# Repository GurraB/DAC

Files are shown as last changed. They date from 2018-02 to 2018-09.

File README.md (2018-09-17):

# DAC
A USB DAC

This is my take on an USB DAC. 

Theoretical specs:
- 16 bit resolution
- fs = 44.1 kHz
- Signal to noise ratio: 127 dB
- THD+N: 0.0004%

Components:

- TI PCM2707c http://www.ti.com/lit/ds/sbfs036b/sbfs036b.pdf
- TI PCM1794a http://www.ti.com/lit/ds/symlink/pcm1794a.pdf
- TI OPA2134 http://www.ti.com/lit/ds/symlink/opa2134.pdf
- TI LM2662 http://www.ti.com/lit/ds/symlink/lm2663.pdf
- TI TPS60501 http://www.ti.com/lit/ds/symlink/tps60500.pdf

This was designed in EAGLE CAD. It is the first PCB I have ever made. The PCM2707c is used as an USB interface, it is automatically detected as a DAC by windows (Linux might need some drivers). The PCM2707c converts the USB signal to i2s and sends it to the PCM1794a. PCM1794a is a high quality DAC that generates the output signal. The signal is then sent to the operational amplifier.

The bottleneck in the system is the PCM2707c since it can only accept 16 bit audio signal.

Future work:
This is the first design that I have made to see if I can make a simple DAC to begin with. In the future I have plans to add an ESP32 to allow for bluetooth connectivity. I have also thought about adding a Raspberry Pi Zero W that can act as a spotify connect device.

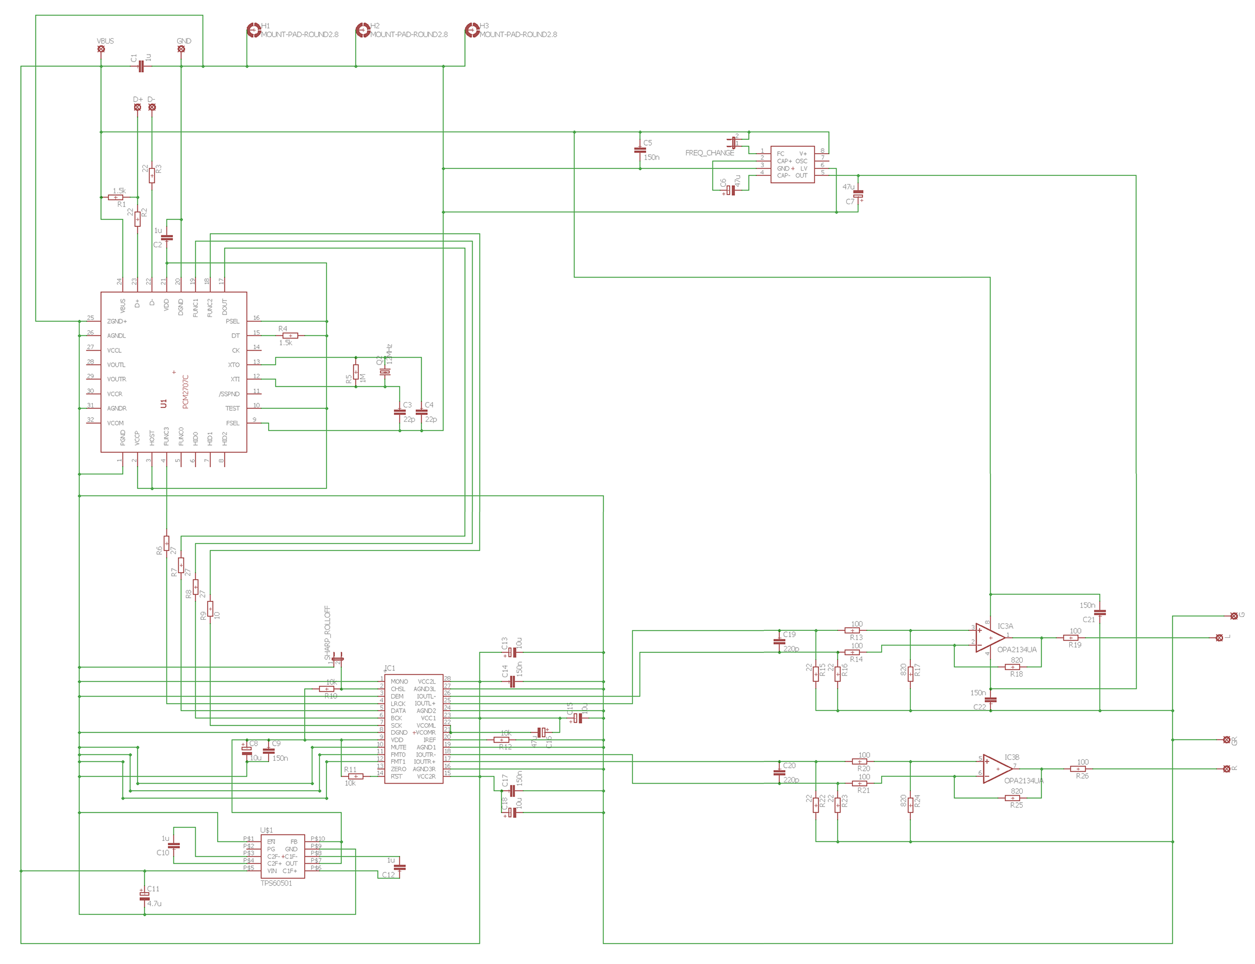
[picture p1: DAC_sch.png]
Picture of the schematic

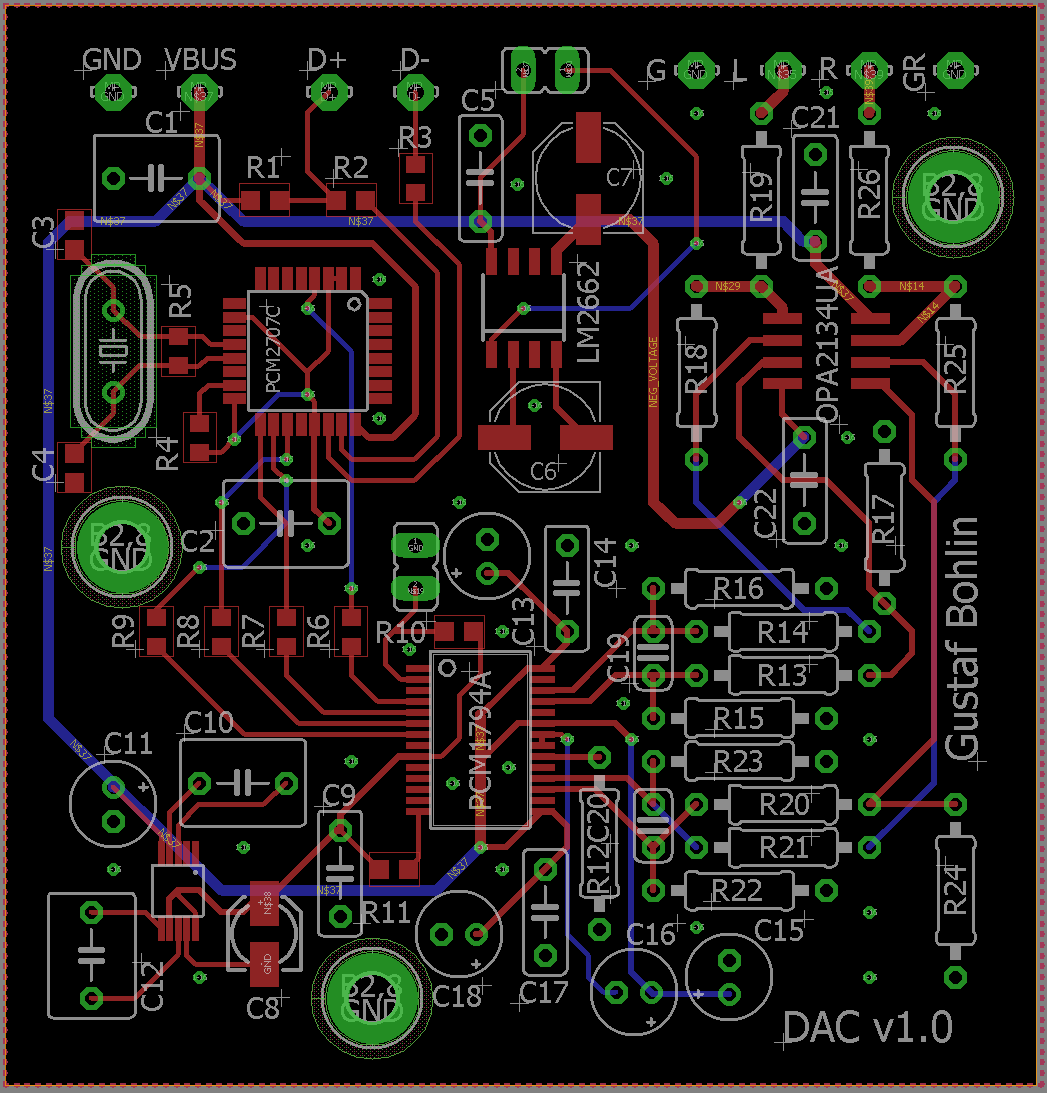
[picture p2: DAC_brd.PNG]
Picture of the board layout

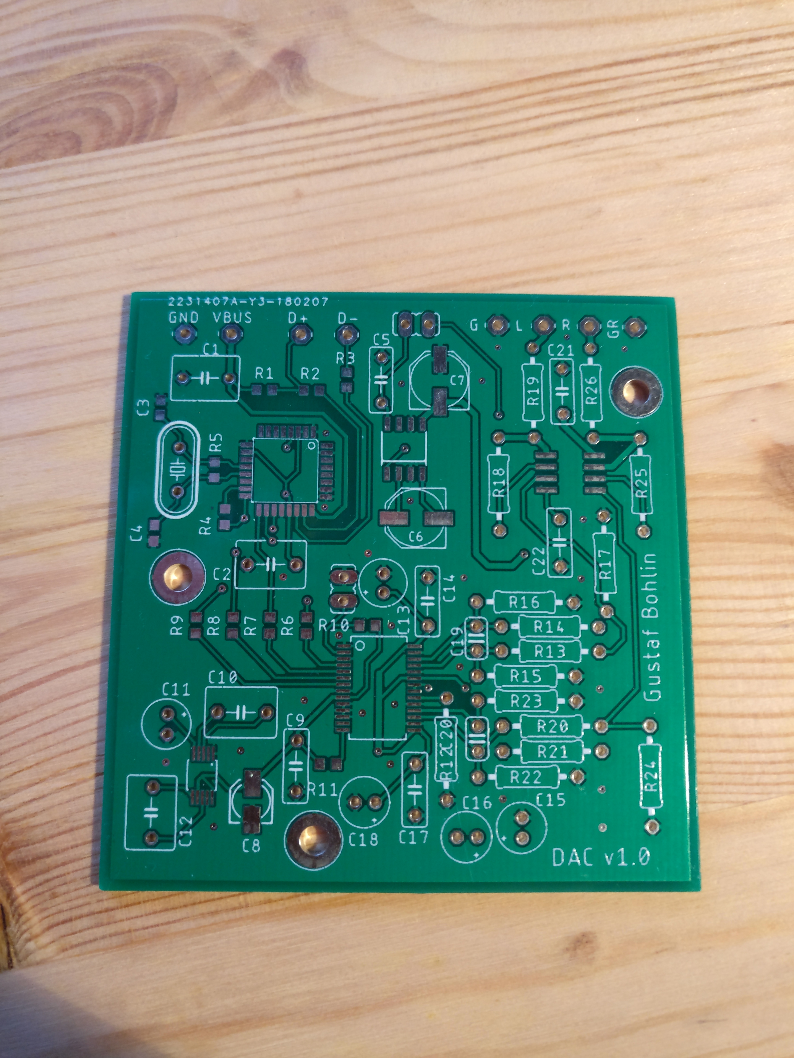
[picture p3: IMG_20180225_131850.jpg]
Picture of finished board without components

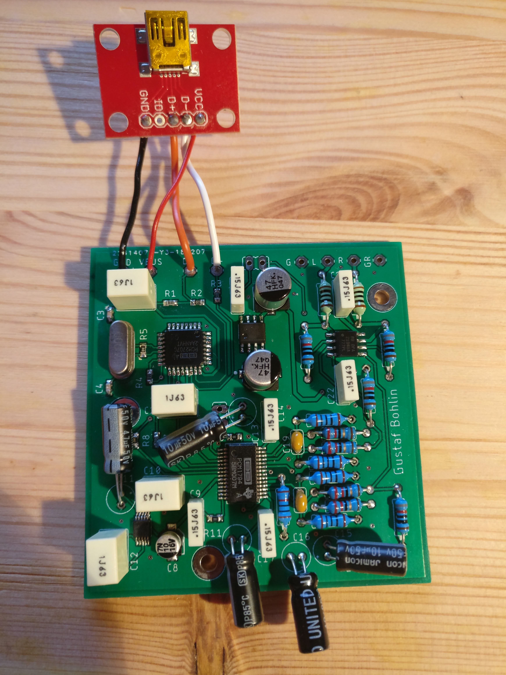
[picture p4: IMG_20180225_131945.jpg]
Picture of finished board with components

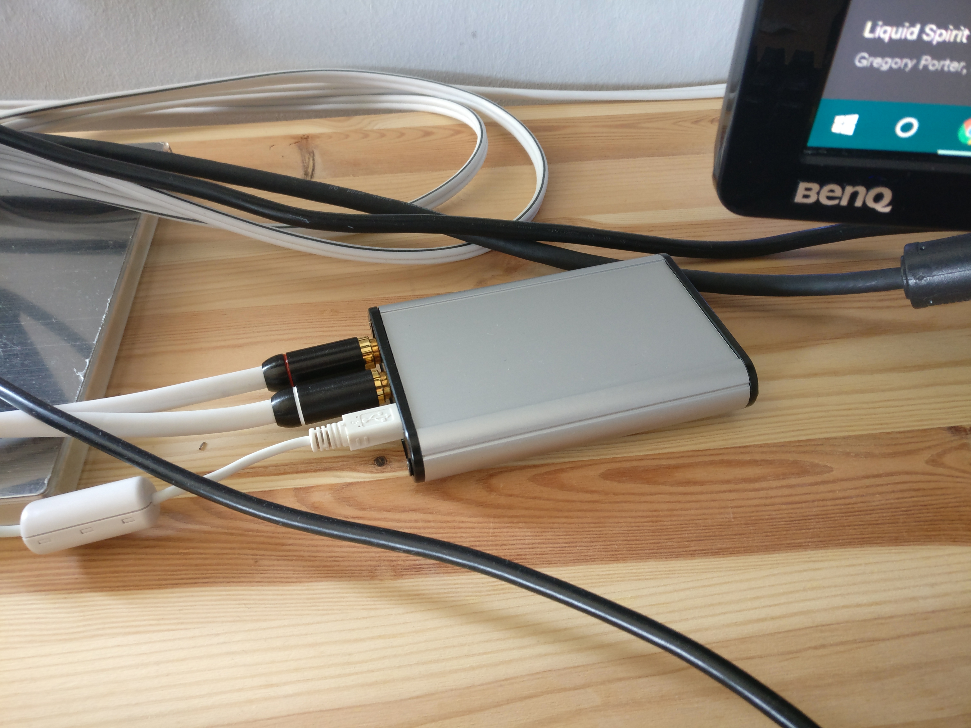
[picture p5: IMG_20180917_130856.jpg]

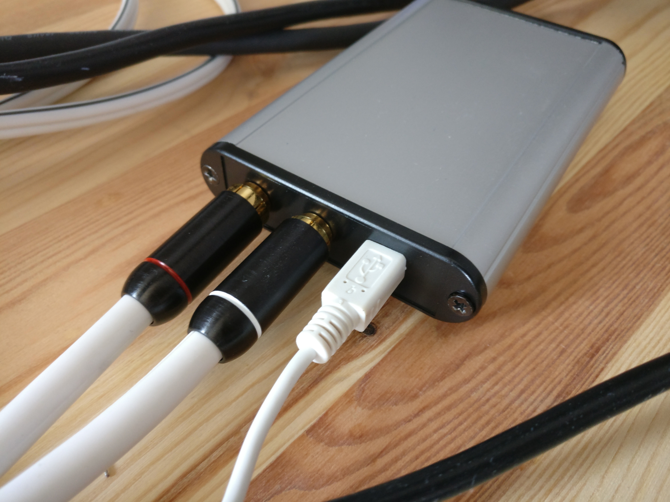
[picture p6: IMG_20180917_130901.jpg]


Design is based upon http://users.abo.fi/jskata/JEDAC/

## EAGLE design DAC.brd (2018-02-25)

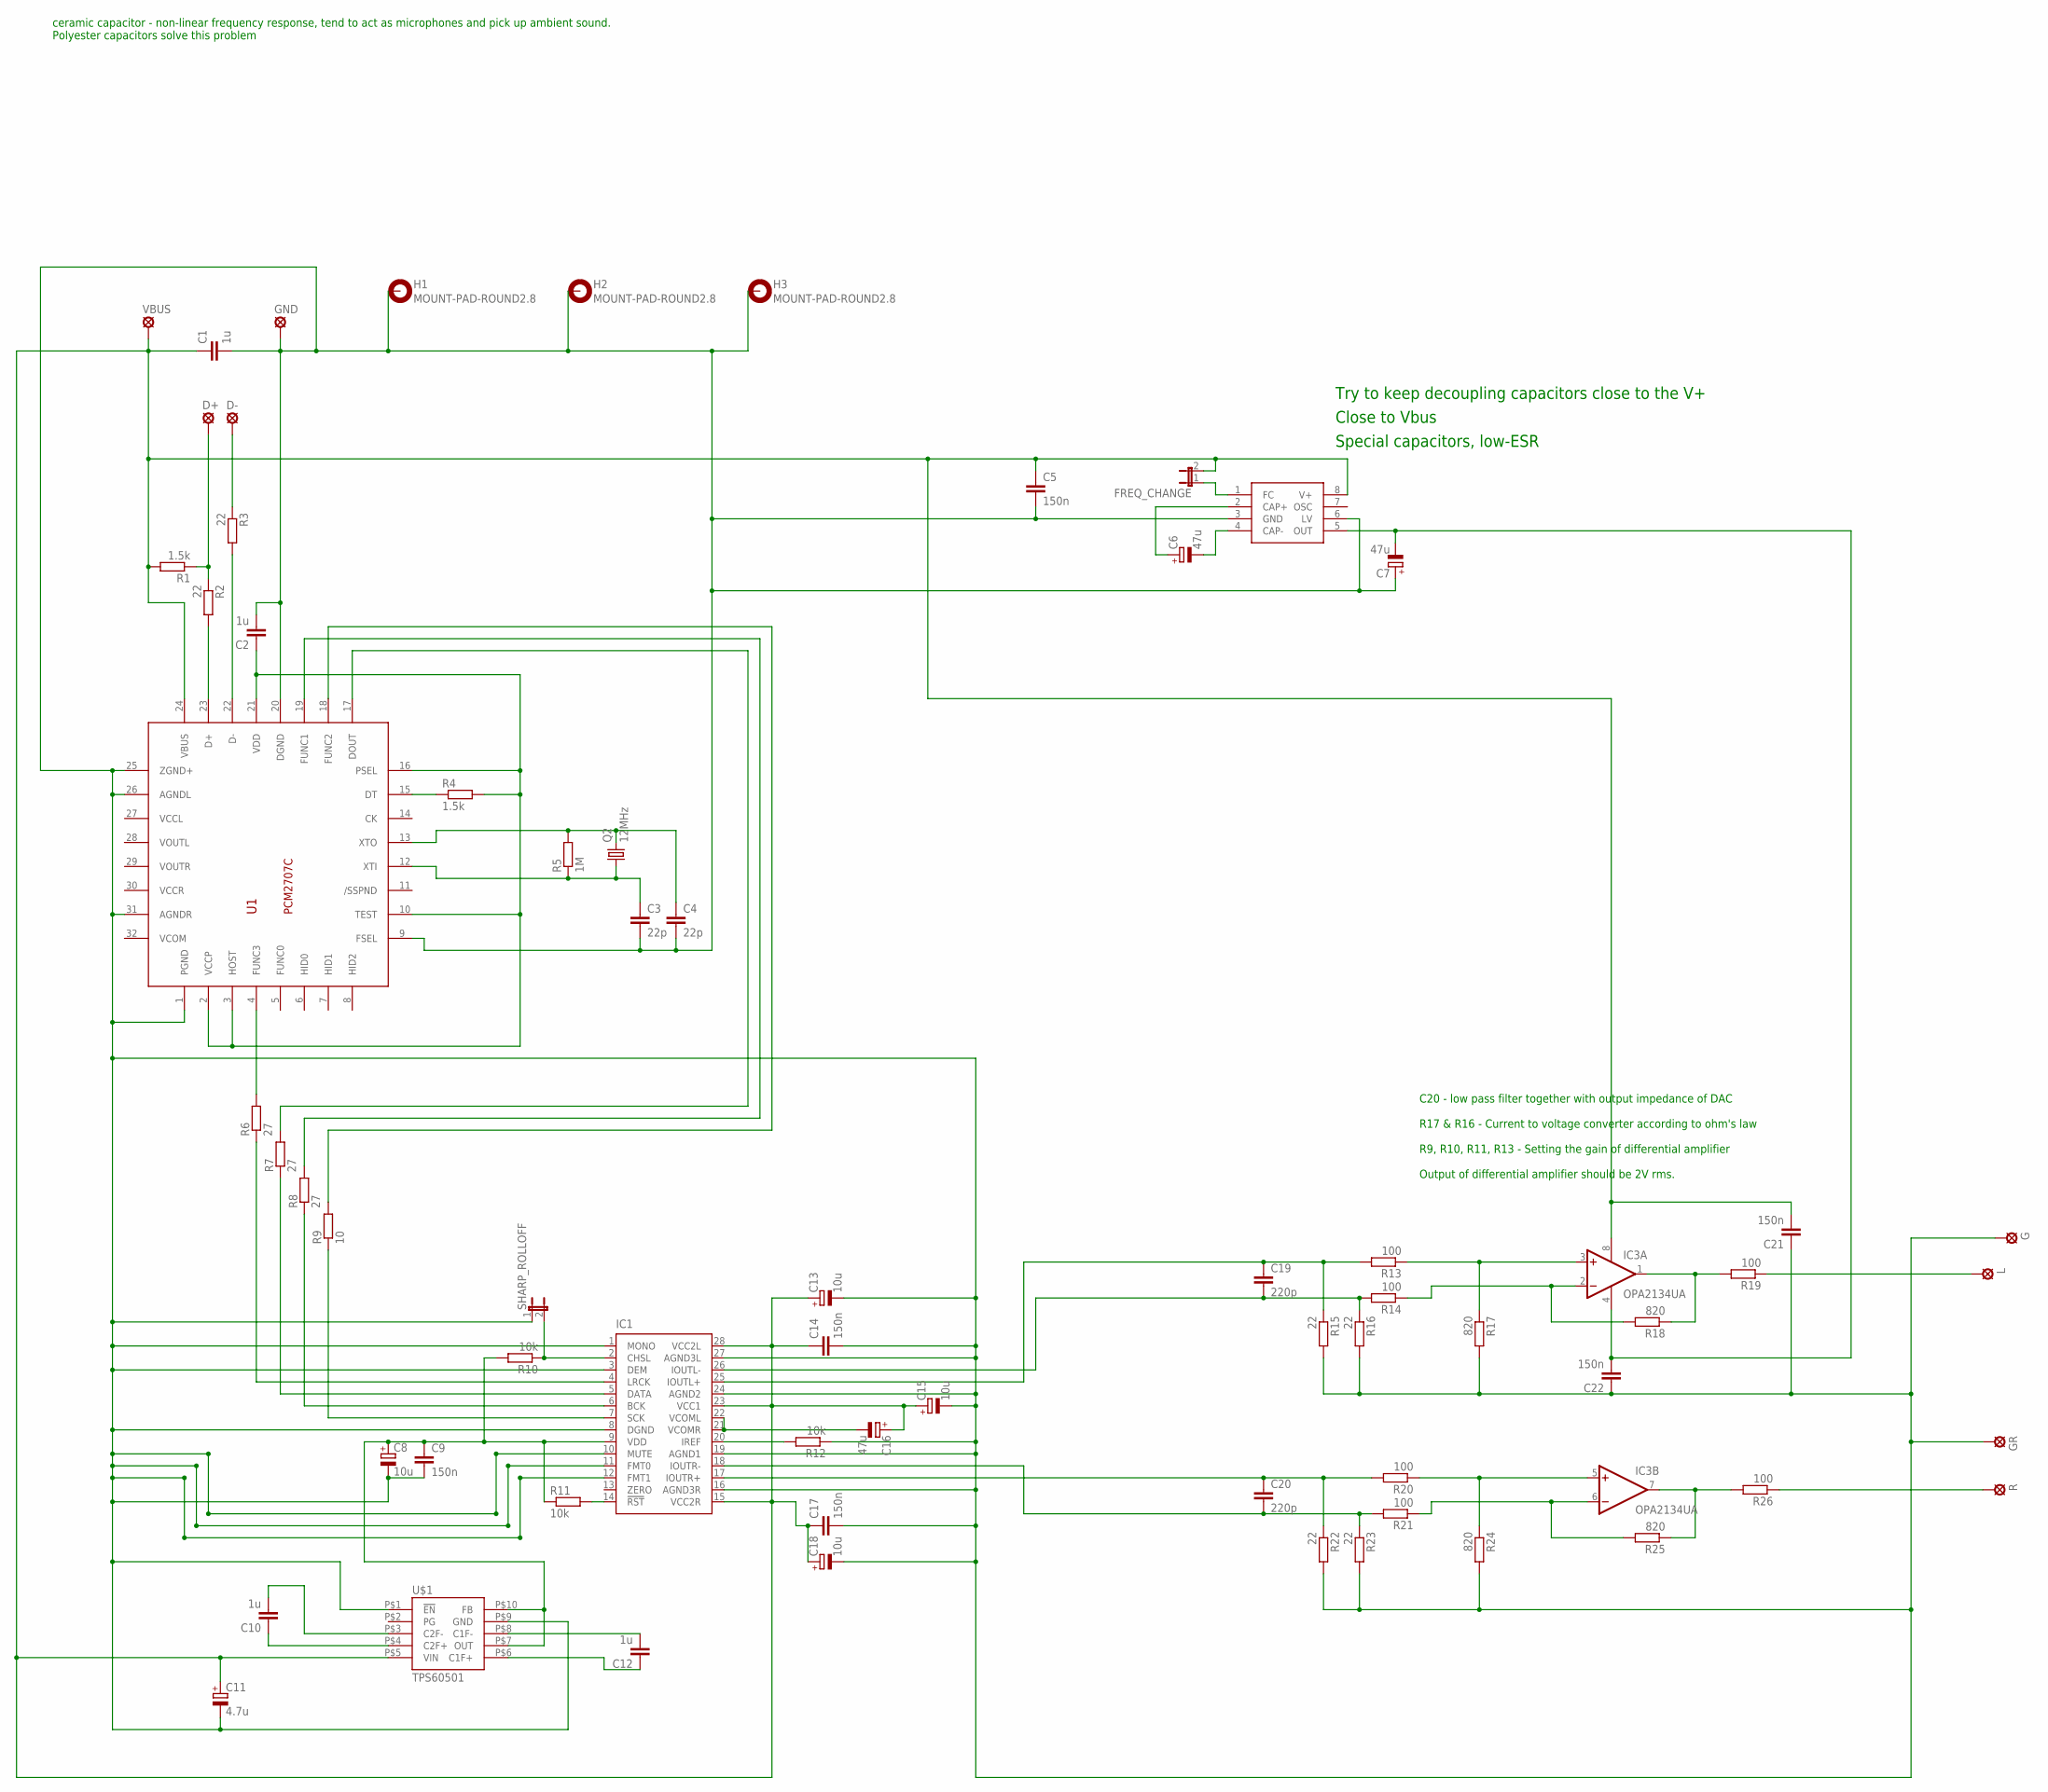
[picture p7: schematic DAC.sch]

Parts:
C1, C2, C10, C12: 1u; C050-050X075
C3, C4: 22p; C0603
C5, C9, C14, C17, C21, C22: 150n; C050-025X075
C6, C7: 47u; PANASONIC_D
C8: 10u; 153CLV-0405
C11: 4.7u; E2-5
C13, C15, C18: 10u; E2-5
C16: 47u; E2-5
C19, C20: 220p; C025-024X044
D+: LSP10
D-: LSP10
FREQ_CHANGE: JP1E; JP1
G: LSP10
GND: LSP10
GR: LSP10
H1, H2, H3: MOUNT-PAD-ROUND2.8; 2,8-PAD
IC1: PCM1794A; SSOP28DB
IC3: OPA2134UA; SO08
L: LSP10
Q2: 12MHz; HC49/S
R: LSP10
R1, R4: 1.5k; R0603
R2, R3: 22; R0603
R5: 1M; R0603
R6, R7, R8: 27; R0603
R9: 10; R0603
R10, R11: 10k; R0603
R12: 10k; 0207/10
R13, R14, R19, R20, R21, R26: 100; 0207/10
R15, R16, R22, R23: 22; 0207/10
R17, R18, R24, R25: 820; 0207/10
SHARP_ROLLOFF: JP1E; JP1
U1: PCM2707C; 32TQFP_PCM2707C
U$1: TPS60501; VSSOP10
U$2: LM2662; SOIC8
VBUS: LSP10

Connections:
D+: D+.MP, R1.1, R2.1
D-: D-.MP, R3.1
GND: C1.2, C2.2, C3.2, C4.2, C5.2, C7.+, C8.-, C9.2, C11.-, C13.-, C14.2, C15.-, C17.2, C18.-, C21.1, C22.1, G.MP, GND.MP, GR.MP, H1.B2,8, H2.B2,8, H3.B2,8, IC1.1 (MONO), IC1.3 (DEM), IC1.8 (DGND), IC1.10 (MUTE), IC1.11 (FMT0), IC1.12 (FMT1), IC1.16 (AGND3R), IC1.19 (AGND1), IC1.24 (AGND2), IC1.27 (AGND3L), R12.1, R15.2, R16.2, R17.2, R22.2, R23.2, R24.2, SHARP_ROLLOFF.1, U1.1 (PGND), U1.9 (FSEL), U1.20 (DGND), U1.25 (ZGND+), U1.26 (AGNDL), U1.31 (AGNDR), U$1.P$1 (!EN), U$1.P$9 (GND), U$2.3 (GND), U$2.6 (LV)
unnamed: R2.2, U1.23 (D+)
unnamed: R3.2, U1.22 (D-)
unnamed: C2.1, R4.2, U1.2 (VCCP), U1.3 (HOST), U1.10 (TEST), U1.16 (PSEL), U1.21 (VDD)
unnamed: R4.1, U1.15 (DT)
unnamed: C4.1, Q2.2, R5.2, U1.13 (XTO)
unnamed: C3.1, Q2.1, R5.1, U1.12 (XTI)
unnamed: C10.1, U$1.P$4 (C2F+)
unnamed: C10.2, U$1.P$3 (C2F-)
unnamed: IC1.20 (IREF), R12.2
unnamed: C12.2, U$1.P$8 (C1F-)
unnamed: C6.-, U$2.4 (CAP-)
unnamed: IC1.5 (DATA), R7.1
unnamed: IC3.2 (-IN), R14.1, R18.2
unnamed: IC3.7 (OUT), R25.1, R26.2
unnamed: C12.1, U$1.P$6 (C1F+)
unnamed: IC1.14 (!RST), R11.2
unnamed: IC1.6 (BCK), R8.1
unnamed: IC1.2 (CHSL), R10.1, SHARP_ROLLOFF.2
unnamed: IC1.4 (LRCK), R6.1
unnamed: R7.2, U1.17 (DOUT)
unnamed: R8.2, U1.19 (FUNC1)
unnamed: R9.2, U1.18 (FUNC2)
unnamed: C19.2, IC1.26 (IOUTL-), R14.2, R16.1
unnamed: C19.1, IC1.25 (IOUTL+), R13.2, R15.1
unnamed: C20.1, IC1.17 (IOUTR+), R20.2, R22.1
unnamed: C20.2, IC1.18 (IOUTR-), R21.2, R23.1
unnamed: IC3.6 (-IN), R21.1, R25.2
unnamed: IC3.1 (OUT), R18.1, R19.2
unnamed: FREQ_CHANGE.1, U$2.1 (FC)
unnamed: C6.+, U$2.2 (CAP+)
unnamed: IC3.3 (+IN), R13.1, R17.1
unnamed: C16.-, IC1.21 (VCOMR), IC1.22 (VCOML)
unnamed: L.MP, R19.1
unnamed: IC3.5 (+IN), R20.1, R24.1
unnamed: C1.1, C5.1, C11.+, C13.+, C14.1, C15.+, C16.+, C17.1, C18.+, C21.2, FREQ_CHANGE.2, IC1.15 (VCC2R), IC1.23 (VCC1), IC1.28 (VCC2L), IC3.8 (V+), R1.2, U1.24 (VBUS), U$1.P$5 (VIN), U$2.8 (V+), VBUS.MP
unnamed: C8.+, C9.1, IC1.9 (VDD), R10.2, R11.1, U$1.P$7 (OUT), U$1.P$10 (FB)
unnamed: R.MP, R26.1
unnamed: IC1.7 (SCK), R9.1
unnamed: R6.2, U1.4 (FUNC3)
NEG_VOLTAGE: C7.-, C22.2, IC3.4 (V-), U$2.5 (OUT)

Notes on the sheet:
Close to Vbus
Special capacitors, low-ESR
Try to keep decoupling capacitors close to the V+
C20 - low pass filter together with output impedance of DAC R17 & R16 - Current to voltage converter according to ohm's law R9, R10, R11, R13 - Setting the gain of differential amplifier Output of differential amplifier should be 2V rms.
ceramic capacitor - non-linear frequency response, tend to act as microphones and pick up ambient sound. Polyester capacitors solve this problem

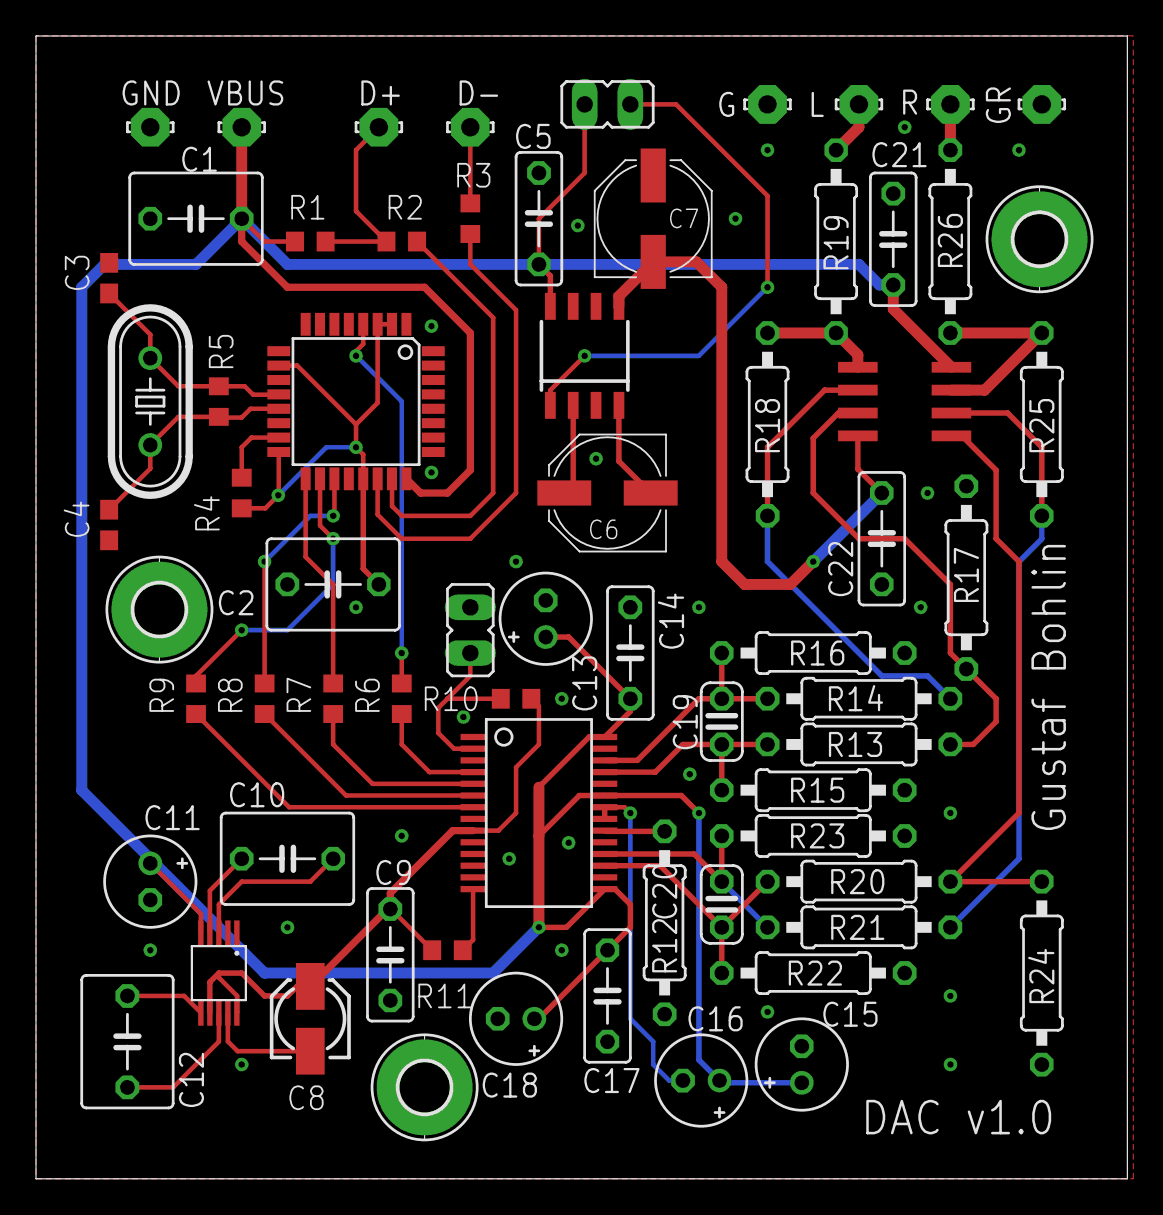
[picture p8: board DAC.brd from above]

Board: 2 copper layers, 60.6 x 63.5 mm, 67 parts (0 on the bottom side), 43 nets.

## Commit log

2018-02-25 Uploaded EAGLE files and pictures
    [DAC.brd, DAC.sch]
2018-02-25 Added pictures of board
